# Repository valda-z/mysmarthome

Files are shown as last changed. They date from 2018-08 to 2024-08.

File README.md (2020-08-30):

# README #

Smart home solution

## To build
- MySmartHomeCore - WEB UI + WEB API backend for units
- SmartHomeCore - raspberry Pi net core based application for communication with devices (HTTP/REST for ESP8266 modules, RS485 for JA82)
- IoT/ESP-WiFi/HeatingRelay - wireless switch for heating and heating motor based on ESP8266
- IoT/ESP-WiFi/OutdoorUnit - Outdoor unit for Dog House, Irrigation and temperature sensors based on ESP8266 (don't forget to insert WIFI Password and unit GUID to variables in INO file)
  - also you have to define ID of dog home temperature sensor, you can run sketch and check logs for 18DS20 MAC adress and than you can change logic in function getTemperatures()

## To install

### MySmartHomeCore
- build Docker image
- configure appconfig.json with desired configuration data

### install SmartHomeCore
- copy app from bin/Debug to raspberry pi `/opt/smarthome`
- register startup script `/opt/smarthome/smarthome.sh` via `update-rc.d`
- configure file appsetting.json (define unit GUID and your Azure web app URL - https preferred)

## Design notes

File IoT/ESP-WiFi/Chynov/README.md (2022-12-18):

# ESP32 / Arduino Mega 2650 based smart home system

Main function:
* alarm system with 8 independent inputs (alarm zones) - simple IO inputs with optical isolation
* temperature sensors for indoor / outdoor
* display unit for temperature / system status
* heating switch on/off based on indoor / outdoor temperature
* remote command module via WiFi for Drazice LX35 photovoltaic clima-unit

## Modules

* MASTER  = Master unit - ESP32
    * Connection to cloud unit
    * 8 IO inputs for alarm
    * 1 IO output for alarm (acoustic siren) - relay
    * 4 IO output for heating - relay
    * alarm logic
    * heating logic
    * LED indicators for maintenance
* SLAVE DISPLAY (A) = Slave unit - ESP32 - display / temperature shield
    * docs:
        * https://github.com/Xinyuan-LilyGO/T5-Ink-Screen-Series
        * https://github.com/goldfish1974/T5-Ink-Screen-Series
        * https://navody.arduino-shop.cz/navody-k-produktum/e-ink-2-13-displej-il0373f.html
    * indoor temperature sensor
    * outdoor temperature sensor
    * eInk display - status info
        * date / time
        * indoor temperature
        * outdoor temperature
        * alarm status
        * heating status
        * LX35 status
* SLAVE RFID (B) = Slave unit - Mega 2560 - 125kHz RFID reader, alarm status indicator
    * RFID reader
    * LED 2 color output (alarm status)
    * beeper

## Communication protocol

Based on RS485 on 9600 baud rate (9600, SERIAL_8N1) with one master unit and slave units.

Master unit is sending query packet each 200 ms to slave units and waits for max 200ms for answer.

Each packets from master starts with character `>` and ends with linux new line `\n`. Each packet from slave unit starts with `<` and ends with linux new line `\n`.

⏎ is used for `\n` symbol in protocol definition.

```
# MASTER - query SLAVE DISPLAY
#-----------------------------------------------------
>AxxxxxxXYZZZ##⏎
│││     │││  │ │
│││     │││  │ └─── NewLine
│││     │││  └───── Hex encoded CRC-8
│││     ││└──────── 3 bytes Lx 35 status
│││     │└───────── Heating status:
│││     │               0 = Off
│││     │               1 = On
│││     └────────── Alarm status:
│││                     0 = Idle
│││                     O = Outgoing delay 
│││                     I = Incoming delay
│││                     1 = Alarm in zone 1
│││                     2 = Alarm in zone 2
│││                     3 = Alarm in zone 3
│││                     4 = Alarm in zone 4
│││                     5 = Alarm in zone 5
│││                     6 = Alarm in zone 6
│││                     7 = Alarm in zone 7
│││                     8 = Alarm in zone 8
││└──────────────── 6 chars - base64 encoded unix time (4 bytes)
│└───────────────── A = request SLAVE DISPLAY
└────────────────── Start character

# SLAVE DISPLAY - answer to MASTER
#-----------------------------------------------------
................
<A+000+000...##⏎
│││   │   │  │ │
│││   │   │  │ └─── NewLine
│││   │   │  └───── Hex encoded CRC-8
│││   │   └──────── 3 chars empty = dots
│││   └──────────── 4 chars - outdoor temperature in Celsius in 1/10 units. First char is sign + or -
││└──────────────── 4 chars - indoor temperature in Celsius in 1/10 units. First char is sign + or -
│└───────────────── A = answer from SLAVE DISPLAY
└────────────────── Start character

# MASTER - query SLAVE RFID
#-----------------------------------------------------
>BX..........##⏎
│││          │ │
│││          │ └─── NewLine
│││          └───── Hex encoded CRC-8
││└──────────────── Alarm status:
││                      0 = Idle
││                      O = Outgoing delay 
││                      I = Incoming delay
││                      1 = Alarm in zone 1
││                      2 = Alarm in zone 2
││                      3 = Alarm in zone 3
││                      4 = Alarm in zone 4
││                      5 = Alarm in zone 5
│└───────────────── B = request SLAVE RFID
└────────────────── Start character

# SLAVE RFID - answer to MASTER
#-----------------------------------------------------
<BX0000000000##⏎
││││         │ │
││││         │ └─── NewLine
││││         └───── Hex encoded CRC-8
│││└─────────────── 10 chars of RFID data if present
││└──────────────── RFID status:
││                      0 = No data
││                      1 = RFID data in packet
│└───────────────── B = answer from SLAVE RFID
└────────────────── Start character

```

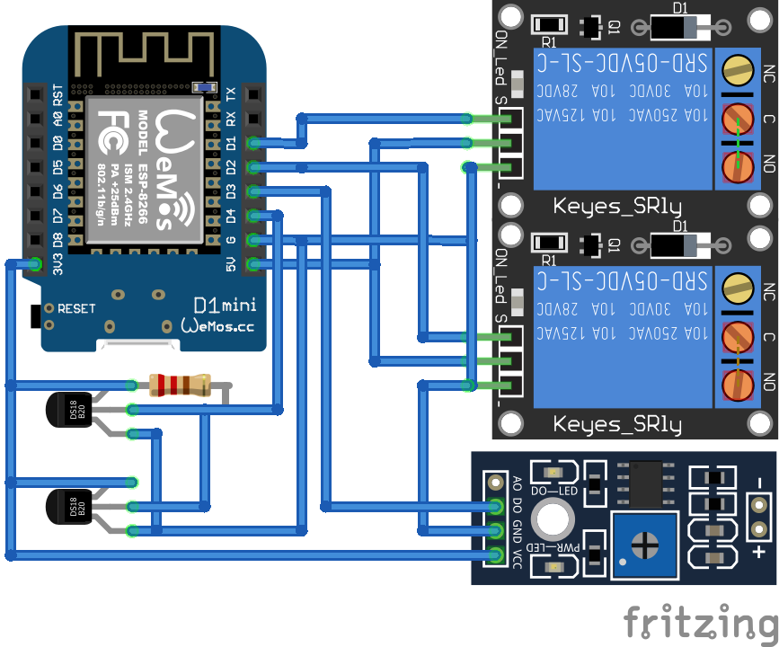
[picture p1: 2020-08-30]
Doc/NodeMCU-OutdoorUnit_bb.png

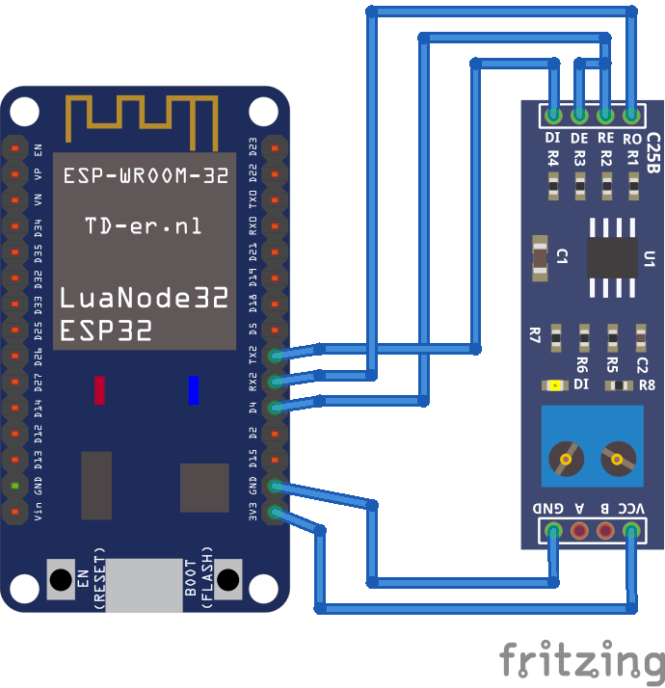
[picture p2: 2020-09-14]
Doc/ESP32-JablotronUnit_bb.png

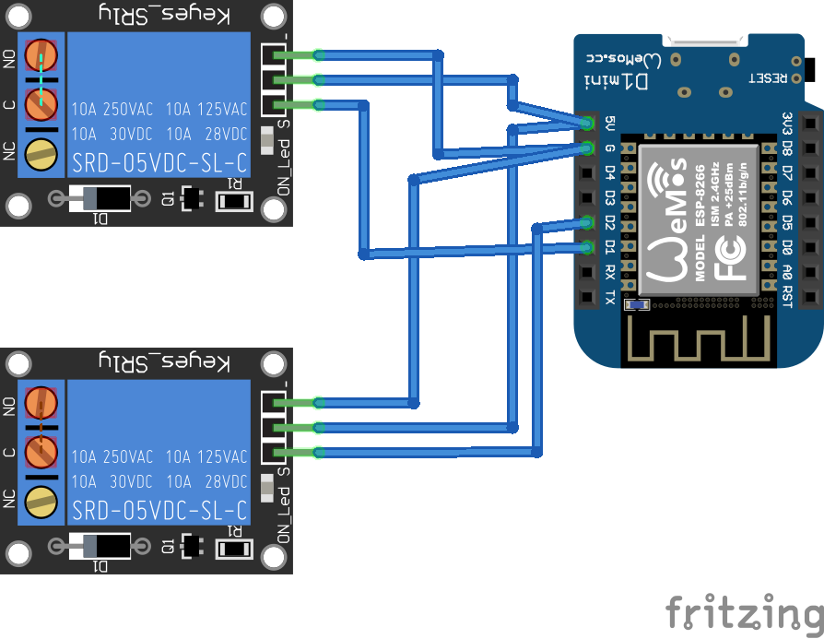
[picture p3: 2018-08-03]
Doc/NodeMCU-HeatingRealy_bb.png

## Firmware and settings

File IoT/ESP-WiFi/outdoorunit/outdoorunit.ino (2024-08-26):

/* *
MySmartHome Outdoor Unit
v 1.0.0
*/

#include <Arduino.h>
#include <ArduinoJson.h>

#include <ezTime.h>

#include <ESP8266WiFi.h>
#include <ESP8266WiFiMulti.h>

#include <ESP8266HTTPClient.h>

#include <WiFiClientSecureBearSSL.h>

#include <OneWire.h>
#include <DallasTemperature.h>

// ############################
// #define UNITID "XXXX"
// #define WIFIPWD "XXXX"
// use include instead
#include "/Users/valda/src/mysmarthome/IoT/ESP-WiFi/outdoorunit/.mysecrets.h"

// Fingerprint for demo URL, expires on June 2, 2019, needs to be updated well before this date
// const uint8_t fingerprint[20] = {0x5A, 0xCF, 0xFE, 0xF0, 0xF1, 0xA6, 0xF4, 0x5F, 0xD2, 0x11, 0x11, 0xC6, 0x1D, 0x2F, 0x0E, 0xBC, 0x39, 0x8D, 0x50, 0xE0};

ESP8266WiFiMulti WiFiMulti;
int wifiConnAttempt = 0;

#define IO_OUT1 5
#define IO_OUT2 4
#define IO_IN 0
#define IO_TEMP 2

// Setup a oneWire instance to communicate with any OneWire devices
OneWire oneWire(IO_TEMP);

// Pass our oneWire reference to Dallas Temperature sensor 
DallasTemperature sensors(&oneWire);

// Number of temperature devices found
int numberOfDevices;
float tempDogHouse = 0;
float tempOut = 0;
bool dataIsWet = false;
bool dataWaterSwitchOn = false;
bool dataDoghouseHeating = false;

float srvDoghouseTemp = 0;
bool srvIrrigationOn = false;
bool srvChristmasOn = false;
String srvWaterOnStart = "";
String srvWaterOnEnd = "";
String srvWater1Start = "";
int srvWater1Int = 0;
String srvWater2Start = "";
int srvWater2Int = 0;

// We'll use this variable to store a found device address
DeviceAddress tempDeviceAddress; 

Timezone MYTIME;


void setup() {

  Serial.begin(115200);
  // Serial.setDebugOutput(true);

  Serial.println();
  Serial.println();
  Serial.println();

  for (uint8_t t = 4; t > 0; t--) {
    Serial.printf("[SETUP] (v1.0.0) WAIT %d...\n", t);
    Serial.flush();
    delay(1000);
  }

  WiFi.mode(WIFI_STA);
  WiFiMulti.addAP("grizzly", WIFIPWD);
  WiFiMulti.addAP("grizzly5G_EXT", WIFIPWD);

  wifiConnAttempt = 0;

  // setup GPIOS
  pinMode(IO_OUT1, OUTPUT); 
  pinMode(IO_OUT2, OUTPUT); 
  digitalWrite(IO_OUT1, HIGH);
  digitalWrite(IO_OUT2, HIGH);
  pinMode(IO_IN, INPUT); 

  // Start up the library
  sensors.begin();
  
  // Grab a count of devices on the wire
  numberOfDevices = sensors.getDeviceCount();
  
  // 
  // BOUDA Found device 0 with address: 289A4DB72719019C
  // OUTTEMP Found device 1 with address: 28631956B5013C8A

  // locate devices on the bus
  Serial.print("Locating devices...");
  Serial.print("Found ");
  Serial.print(numberOfDevices, DEC);
  Serial.println(" devices.");

  // Loop through each device, print out address
  for(int i=0;i<numberOfDevices; i++){
    // Search the wire for address
    if(sensors.getAddress(tempDeviceAddress, i)){
      Serial.print("Found device ");
      Serial.print(i, DEC);
      Serial.print(" with address: ");
      printAddress(tempDeviceAddress);
      Serial.println();
    } else {
      Serial.print("Found ghost device at ");
      Serial.print(i, DEC);
      Serial.print(" but could not detect address. Check power and cabling");
    }
  }

  setInterval(60);
  MYTIME.setLocation("Europe/Prague");
  // wait for sync time
  waitForSync(60);

  setNTP();
  digitalClockDisplay();

}

void setNTP(){
  events();
  //configTime("CET-1CEST,M3.5.0,M10.5.0/3", "pool.ntp.org", "time.nist.gov");
}

// function to print a device address
void printAddress(DeviceAddress deviceAddress) {
  for (uint8_t i = 0; i < 8; i++){
    if (deviceAddress[i] < 16) Serial.print("0");
      Serial.print(deviceAddress[i], HEX);
  }
}

void digitalClockDisplay() {
  //time_t tnow = time(nullptr);
  //Serial.println(ctime(&tnow));

  Serial.println("UTC RFC3339_EXT: " + UTC.dateTime(RFC3339_EXT));
  // PRG time
  Serial.println("Prague RFC3339_EXT: " + MYTIME.dateTime(RFC3339_EXT));
}

void getWet(){
  dataIsWet = digitalRead(IO_IN)==0;
}

void getTemperatures(){
    sensors.requestTemperatures(); // Send the command to get temperatures
    
    // Loop through each device, print out temperature data
    for(int i=0;i<numberOfDevices; i++){
      // Search the wire for address
      if(sensors.getAddress(tempDeviceAddress, i)){
        // Output the device ID
        Serial.print("Temperature for device (");
        Serial.print(i,DEC);
        Serial.print(":");
        printAddress(tempDeviceAddress);
        Serial.print(") : ");
        // Print the data
        float tempC = sensors.getTempC(tempDeviceAddress);
        Serial.println(tempC);
        // check doghouse device 
        if( tempDeviceAddress[0] == 0x28 &&
            tempDeviceAddress[1] == 0x9A &&
            tempDeviceAddress[2] == 0x4D &&
            tempDeviceAddress[3] == 0xB7 &&
            tempDeviceAddress[4] == 0x27 &&
            tempDeviceAddress[5] == 0x19 &&
            tempDeviceAddress[6] == 0x01 &&
            tempDeviceAddress[7] == 0x9C  ){
          Serial.print("DOGHOUSE device ...");
          Serial.println();
          tempDogHouse = tempC;
        }else{
          tempOut = tempC;
        }
      }
    }
}

// {"data":[{"outsidetemp":99.9,"doghousetemp":0.0,"doghouseheating":false,
//  "waterswitchon":false,"iswet":false,"timestamp":"2019-08-27T11:25:34.6779085+02:00"}
String createJSON(){
  DynamicJsonDocument doc(2048);
  String ret;

  doc["data"][0]["outsidetemp"] = tempOut;
  doc["data"][0]["doghousetemp"] = tempDogHouse;
  doc["data"][0]["doghouseheating"] = dataDoghouseHeating;
  doc["data"][0]["waterswitchon"] = dataWaterSwitchOn;
  doc["data"][0]["iswet"] = dataIsWet;
  doc["data"][0]["timestamp"] = MYTIME.dateTime(RFC3339_EXT);

  serializeJson(doc, ret);

  Serial.print("JSON for send:\n");
  Serial.print(ret);
  Serial.print("\n");
  return ret;
}

String convertWStart(String hr){
  String ret = MYTIME.dateTime(RFC3339_EXT).substring(0,11) + hr + ":00";
  return ret;
}

void sendSSL(){
    std::unique_ptr<BearSSL::WiFiClientSecure>client(new BearSSL::WiFiClientSecure);

    //client->setFingerprint(fingerprint);
    client->setInsecure();

    // https://arduinojson.org/v6/how-to/use-arduinojson-with-esp8266httpclient/

    HTTPClient https;

    Serial.print("[HTTPS] begin...\n");
    if (https.begin(*client, "https://myhome.valda.cloud/api/Device/Log?id=" UNITID)) {  // HTTPS
      https.addHeader("Content-Type", "application/json");

      Serial.print("[HTTPS] POST...\n");
      // start connection and send HTTP header
      int httpCode = https.POST(createJSON());

      // httpCode will be negative on error
      if (httpCode > 0) {
        // HTTP header has been send and Server response header has been handled
        Serial.printf("[HTTPS] POST... code: %d\n", httpCode);

        // file found at server
        if (httpCode == HTTP_CODE_OK || httpCode == HTTP_CODE_MOVED_PERMANENTLY) {
          DynamicJsonDocument doc(2048);
          String pload = https.getString();
          Serial.println(pload);
          deserializeJson(doc, pload);
          
          srvDoghouseTemp = doc["dogontemp"].as<float>();
          srvChristmasOn = doc["christmasOn"].as<bool>();
          srvIrrigationOn = doc["irrigationOn"].as<bool>();
          srvWaterOnStart = doc["water"]["from"].as<String>();
          srvWaterOnStart = srvWaterOnStart.substring(0,19);
          srvWaterOnEnd = doc["water"]["to"].as<String>();
          srvWaterOnEnd = srvWaterOnEnd.substring(0,19);
          if(srvIrrigationOn){
            srvWater1Start = convertWStart(doc["wateritems"][0]["starthour"].as<String>());
            srvWater1Int = doc["wateritems"][0]["intervalsec"].as<int>();
            srvWater2Start = convertWStart(doc["wateritems"][1]["starthour"].as<String>());
            srvWater2Int = doc["wateritems"][1]["intervalsec"].as<int>();
          }else{
            srvWater1Start = "0000";
            srvWater1Int = 0;
            srvWater2Start = "0000";
            srvWater2Int = 0;
          }
        }
      } else {
        Serial.printf("[HTTPS] POST... failed, error: %s\n", https.errorToString(httpCode).c_str());
      }

      https.end();
    } else {
      Serial.printf("[HTTPS] Unable to connect\n");
    }  
}

void setSSR(){
  digitalWrite(IO_OUT1, dataDoghouseHeating ? LOW : HIGH);
  digitalWrite(IO_OUT2, dataWaterSwitchOn ? LOW : HIGH);
}

void processLogic(){
  Serial.println("------ PROCESS LOGIC ------");
  Serial.print("srvChristmasOn: "); Serial.println(srvChristmasOn);
  Serial.print("srvIrrigationOn: "); Serial.println(srvIrrigationOn);
  Serial.print("srvDoghouseTemp: "); Serial.println(srvDoghouseTemp);
  Serial.print("srvWaterOnStart: "); Serial.println(srvWaterOnStart);
  Serial.print("srvWaterOnEnd: "); Serial.println(srvWaterOnEnd);
  Serial.print("srvWater1Start: "); Serial.println(srvWater1Start);
  Serial.print("srvWater1Int: "); Serial.println(srvWater1Int);
  Serial.print("srvWater2Start: "); Serial.println(srvWater2Start);
  Serial.print("srvWater2Int: "); Serial.println(srvWater2Int);

  //water LOGIC
  dataWaterSwitchOn = false;
  String wnow = UTC.dateTime(RFC3339_EXT).substring(0,19);
  if(srvWaterOnStart<=wnow && srvWaterOnEnd>=wnow){
    dataWaterSwitchOn = true;
    Serial.println(" -> switch on water = forced switch on");
  }else{
    if(srvIrrigationOn && (!dataIsWet || srvChristmasOn)){
      if(srvWater1Start<=MYTIME.dateTime(RFC3339_EXT).substring(0,19) 
          && srvWater1Start>=(MYTIME.dateTime(MYTIME.now() - srvWater1Int, RFC3339_EXT).substring(0,19))){
        dataWaterSwitchOn = true;
        Serial.println(" -> switch on water = timeinterval for 1");
      }
      if(srvWater2Start<=MYTIME.dateTime(RFC3339_EXT).substring(0,19) 
          && srvWater2Start>=(MYTIME.dateTime(MYTIME.now() - srvWater2Int, RFC3339_EXT).substring(0,19))){
        dataWaterSwitchOn = true;
        Serial.println(" -> switch on water = timeinterval for 2");
      }
    }
  }

  // heating LOGIC
  if(dataDoghouseHeating){
    if((srvDoghouseTemp+0.5)<tempDogHouse){
      dataDoghouseHeating = false;
      Serial.println(" -> switch off heating");
    }
  }else{
    if(srvDoghouseTemp>tempDogHouse){
      dataDoghouseHeating = true;
      Serial.println(" -> switch on heating");
    }
  }
}

void loop() {

  setNTP();

  digitalClockDisplay();

  getTemperatures();

  getWet();

  // wait for WiFi connection
  if ((WiFiMulti.run() == WL_CONNECTED)) {
    wifiConnAttempt = 0;
    sendSSL();
  }else{
    wifiConnAttempt++;
    Serial.printf("Wifi not connected, next attempt: %d\n", wifiConnAttempt);
    if(wifiConnAttempt>5){
      Serial.println("WiFi error - trying to reset ..."); 
      ESP.restart();   
    }
  }

  processLogic();

  setSSR();

  Serial.println("Wait 10s before next round...");
  delay(10000);
}

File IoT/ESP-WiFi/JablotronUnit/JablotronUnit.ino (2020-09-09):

#include <ArduinoJson.h>

#include <WiFi.h>
#include <WiFiMulti.h>
#include <WiFiClient.h>
#include <WebServer.h>
#include <ESPmDNS.h>

#include <ezTime.h>

#include <HTTPClient.h>

// ------------ DEBUG / TRACE
//#define STRACE

// Log serial device
#ifdef STRACE
#define LOG Serial
#else
#define LOG if(false) Serial
#endif

// ------------ defines

QueueHandle_t queue;
int queueSize = 10;

typedef enum {
    ALARMCMD_ARM,
    ALARMCMD_DISARM,
    ALARMCMD_ARM_A,
    ALARMCMD_ARM_B,
    ALARMCMD_ARM_ABC,
    ALARMCMD_NONE
} AlarmCommands;

WebServer server(11080);

TaskHandle_t Task0;

Timezone MYTIME;

WiFiMulti WiFiMulti;

int sslSendDelay = 0;

// https://forum.arduino.cc/index.php?topic=610249.0
// https://navody.arduino-shop.cz/navody-k-produktum/esp32-a-hardwarova-seriova-linka.html
#define RX1 16
#define TX1 17
#define HWSerialRENEG 4
HardwareSerial hwSerial(1);

// ############################
// #define UNITID "XXXX"
// #define WIFIPWD "XXXX"
// use include instead
#include "C:\Src\MySmartHome\IoT\ESP-WiFi\JablotronUnit\.mysecrets.h"

typedef enum {
    JAB_IDLE,
    JAB_ARMED,
    JAB_OUTCOMMINGDELAY,
    JAB_INCOMMINGDELAY,
    JAB_ALARM,
    JAB_DISCONNECTED
} JablotronAlarmState;

typedef enum {
    JAB_ZONE_A,
    JAB_ZONE_B,
    JAB_ZONE_ABC,
    JAB_ZONE_NONE
} JablotronAlarmZone;

struct JABLOTRONDATA {
  bool ledA;
  bool ledB;
  bool ledC;
  bool ledWarning;
  bool ledBacklight;
  time_t lastContact;
  /// 0x00 - Idle
  /// 0x06 - Alarm
  /// 0x0C - Outcomming timeout
  /// 0x0D - Incomming timeout
  /// 0x10 - Active detector
  uint8_t messageId;
  uint8_t deviceId;
  uint8_t msgCRC;
  JablotronAlarmState state;
  JablotronAlarmZone zone;
  bool isMovementThere;
  time_t lastMove;
};

JABLOTRONDATA jadata = {false,false,false,false,false,0,0,0,0,JAB_DISCONNECTED, JAB_ZONE_NONE, false, 0};

uint8_t jabRecBuf[10] = {0,0,0,0,0,0,0,0,0,0};
int jabBufIndex = 0;
AlarmCommands jabCmd = ALARMCMD_NONE;

void handleRoot() {
  server.send(200, "text/plain", (jabIsMoving()?"1":"0"));
}

void handleNotFound() {

  String message = "File Not Found\n\n";
  message += "URI: ";
  message += server.uri();
  message += "\nMethod: ";
  message += (server.method() == HTTP_GET) ? "GET" : "POST";
  message += "\nArguments: ";
  message += server.args();
  message += "\n";
  for (uint8_t i = 0; i < server.args(); i++) {
    message += " " + server.argName(i) + ": " + server.arg(i) + "\n";
  }
  server.send(404, "text/plain", message);
}


void setNTP(){
  events();
  //configTime("CET-1CEST,M3.5.0,M10.5.0/3", "pool.ntp.org", "time.nist.gov");
}

void digitalClockDisplay() {
  //time_t tnow = time(nullptr);
  //LOG.println(ctime(&tnow));

  LOG.println("UTC RFC3339_EXT: " + UTC.dateTime(RFC3339_EXT));
  // PRG time
  LOG.println("Prague RFC3339_EXT: " + MYTIME.dateTime(RFC3339_EXT));
  LOG.print("UTC.now: "); LOG.println(UTC.now());
}

void setup(void) {

  Serial.begin(115200);

  queue = xQueueCreate( queueSize, sizeof( AlarmCommands ) );

  hwSerial.begin(9600, SERIAL_8N1, RX1, TX1);

  pinMode(HWSerialRENEG, OUTPUT);
  digitalWrite(HWSerialRENEG, LOW);

  if(queue == NULL){
    LOG.println("Error creating the queue !!");
    delay(1000);
    ESP.restart();
  }

  WiFi.mode(WIFI_STA);
  WiFiMulti.addAP("grizzly", WIFIPWD);
  WiFiMulti.addAP("grizzly5G_EXT", WIFIPWD);

  int i =0;
  LOG.print("WiFi connecting ."); 
  while(WiFiMulti.run() == WL_CONNECTED){
    if ((WiFiMulti.run() == WL_CONNECTED)) {
      LOG.println(".");
      LOG.println("WiFi connected"); 
      break;
    }
    i++;
    if(i>120){
      LOG.println("WiFi error - trying to reset ..."); 
      ESP.restart();   
    }
    delay(1000);
    LOG.print(".");
  }

  server.on("/", handleRoot);
  server.on("/heating.api", handleRoot);
  server.onNotFound(handleNotFound);

  server.begin();
  LOG.println("HTTP server started");
  LOG.print("setup() running on core ");
  LOG.println(xPortGetCoreID());

   xTaskCreatePinnedToCore(
                    Task0code,   /* Task function. */
                    "Task0",     /* name of task. */
                    10000,       /* Stack size of task */
                    NULL,        /* parameter of the task */
                    1,           /* priority of the task */
                    &Task0,      /* Task handle to keep track of created task */
                    0);          /* pin task to core 0 */   

  setInterval(60);
  MYTIME.setLocation("Europe/Prague");
  // wait for sync time
  waitForSync(60);

  setNTP();
  digitalClockDisplay();
}

// MySmartHome communication
String createJSON(String execcmd){
  DynamicJsonDocument doc(2048);
  String ret;

  doc["data"][0]["timestamp"] = MYTIME.dateTime(RFC3339_EXT);
  doc["data"][0]["armedzone"] = jabAlarmZoneToString(jadata.zone);
  doc["data"][0]["commandexecuted"] = execcmd;
  doc["data"][0]["connected"] = jabIsConnected();
  doc["data"][0]["deviceid"] = jadata.deviceId;
  doc["data"][0]["led_a"] = jadata.ledA;
  doc["data"][0]["led_b"] = jadata.ledB;
  doc["data"][0]["led_backlight"] = jadata.ledBacklight;
  doc["data"][0]["led_c"] = jadata.ledC;
  doc["data"][0]["led_warning"] = jadata.ledWarning;
  doc["data"][0]["state"] = jabAlarmStateToString(jadata.state);
  doc["data"][0]["isalive"] = jabIsConnected();

  serializeJson(doc, ret);

  LOG.print("JSON for send:\n");
  LOG.print(ret);
  LOG.print("\n");
  return ret;
}

String sendSSL(String execcmd){
    String ret = "";
    HTTPClient https;

    LOG.print("[HTTPS] begin...\n");
    if (https.begin("https://myhome.valda.cloud/api/Jablotron/Log?id=" UNITID)) {  // HTTPS
      https.addHeader("Content-Type", "application/json");

      LOG.print("[HTTPS] POST...\n");
      // start connection and send HTTP header
      int httpCode = https.POST(createJSON(execcmd));

      // httpCode will be negative on error
      if (httpCode > 0) {
        // HTTP header has been send and Server response header has been handled
        LOG.printf("[HTTPS] POST... code: %d\n", httpCode);

        // file found at server
        if (httpCode == HTTP_CODE_OK || httpCode == HTTP_CODE_MOVED_PERMANENTLY) {
          DynamicJsonDocument doc(2048);
          String pload = https.getString();
          LOG.print("[HTTPS] Payload from server: ");
          LOG.println(pload);
          deserializeJson(doc, pload);
          
          ret = doc["commandtoexecute"].as<String>();

        }
      } else {
        LOG.printf("[HTTPS] POST... failed, error: %s\n", https.errorToString(httpCode).c_str());
      }

      https.end();
    } else {
      LOG.printf("[HTTPS] Unable to connect\n");
    }  

    return ret;
}

void executeCMD(String cmd){
  AlarmCommands c = ALARMCMD_DISARM;
  if(cmd=="ARM"){
    c = ALARMCMD_ARM;
  }else if(cmd="DISARM"){
    c = ALARMCMD_DISARM;
  }else if(cmd="ARM_A"){
    c = ALARMCMD_ARM_A;
  }else if(cmd="ARM_B"){
    c = ALARMCMD_ARM_B;
  }else if(cmd="ARM_ABC"){
    c = ALARMCMD_ARM_ABC;
  }
  xQueueSend(queue, &c, 500);
}
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

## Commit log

2018-08-01 schematic for outdoor unit
    [OutdoorUnit.fzz]
2018-08-02 schematic for heating shield
    [NodeMCU-HeatingRealy.fzz]
2019-07-15 unstable HW pin for moisture sensor - software noise filtering applied
2020-08-30 wiring for outdoor unit
    [NodeMCU-OutdoorUnit.fzz]
2020-09-02 first version of Jablotron on ESP32
2020-09-09 final ESP32 jablotron unit, cleanup
2020-09-09 fix state machine for alarm states
    [JablotronUnit.ino]
2020-09-14 Docs for IoT
    [ESP32-JablotronUnit.fzz]
2022-12-18 fix doghouse heating
